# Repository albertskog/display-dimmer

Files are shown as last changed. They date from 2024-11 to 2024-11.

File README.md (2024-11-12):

# Display Dimmer

A pair of physical buttons to control the brightness of a pair of external monitors over HDMI.

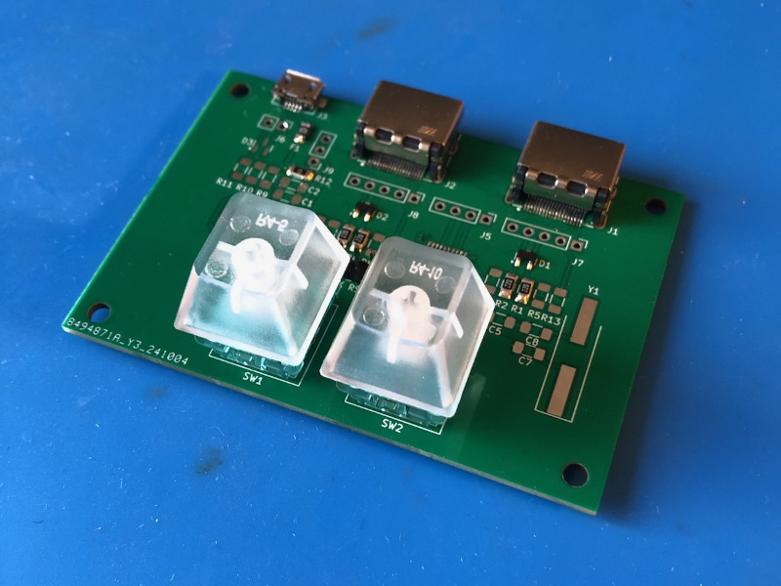
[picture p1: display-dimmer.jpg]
Display Dimmer hardware


## Why?

My USB-C port replicator does not pass on brightness commands to my monitors.

## How?

HDMI has a control channel called DDC. Hook this board up to a spare HDMI port on a monitor and use the buttons to control the brightness.

# Hardware Considerations

Here are some design considerations that were taken into account.

## VCC Voltage

The board has a footprint for a 3.3 V regulator and also a footprint for a 0 Ohm bypass to use 5 V directly from USB. HDMI signaling is 5 V and the CH32V003 can run at 5 V, but both also work at 3.3 V. I have used the 5 V option.

## Pull-up Resistors

On my monitors, the I2C lines are already pulled up to 5 V internally. The PCB has footprints for additional pull-up, but I found it works fine without populating them.

## USB

The board has a USB connector for power. The data lines are connected to GPIO pins for possible future use.

> Only GPIOs 0-4 can be used for USB D+/D- due to limits of the [c.andi](https://msyksphinz-self.github.io/riscv-isadoc/html/rvc.html#c-andi) instruction which can only hold a 5 bit value.
> You **cannot use** PC5-PC7 and PD5-PD7 for D+/D-!

[GitHub - cnlohr/rv003usb: CH32V003 RISC-V Pure Software USB Controller](https://github.com/cnlohr/rv003usb)

## BOM

| Amount | Part | Name | Source |
|---|---|---|---|
| 1x | MCU | CH32V003F4P6 | WCH on Aliexpress |
| 2x | HDMI connector | 685119134923 | [Electrokit](https://www.electrokit.com/hdmi-hona-19p-pcb-smd-wrth) |
| 1x | Micro USB connector | 629105136821 | [Electrokit](https://www.electrokit.com/usb-micro-b-kontakt-smd) |
| 2x | Buttons | MX-style | |
| 1x | Fuse | 1206L025YR | [Electrokit](https://www.electrokit.com/polyswitch-16v-0.25a-smd) |
| 4x | Protection resistor | 1206 22R | |
| 2x | ESD protection | NUP2105LT1G  | [Electrokit](https://www.electrokit.com/nup2105lt1g-sot23-3-tvs-diod) |
| 1x | 5 V bypass | 1206 0R | |

### Not mounted

| Amount | Part | Name | Source |
|---|---|---|---|
| 4x | Pull-up resistor | 1206 10K | |
| 1x | 3.3 V LDO | LDI1117-3.3H | [Electrokit](https://www.electrokit.com/ldi1117-3.3h-sot-223-spanningsregulator-ldo-3.3v) |
| 1x | Crystal 24 MHz | HC49/U4H | [Electrokit](https://www.electrokit.com/kristall-24.000mhz-smd-hc49/u4h) |

# Firmware

There are three firmware options:

1. The proof-of-concept written in Micropython on a Raspberry Pi RP2040.
2. The prototype firmware written in Platformio/Arduino C++ on a WCH CH32V003 devkit.
3. The final firmware written in Rust on the custom PCB.

## DDC Commands

DDC commands are hard-coded in the firmware. The payloads were generated from a slightly modified version of [python-ddcci](https://github.com/Informatic/python-ddcci)

| Command | Data |
|---|---|
| Set 0% | `[0x51, 0x84, 0x3, 0x10, 0x0, 0x0, 0xa8]` |
| Set 10% | `[0x51, 0x84, 0x3, 0x10, 0x0, 0xa, 0xa2]` |
| Set 20% | `[0x51, 0x84, 0x3, 0x10, 0x0, 0x14, 0xbc]` |
| Set 30% | `[0x51, 0x84, 0x3, 0x10, 0x0, 0x1e, 0xb6]` |
| Set 40% | `[0x51, 0x84, 0x3, 0x10, 0x0, 0x28, 0x80]` |
| Set 50% | `[0x51, 0x84, 0x3, 0x10, 0x0, 0x32, 0x9a]` |
| Set 60% | `[0x51, 0x84, 0x3, 0x10, 0x0, 0x3c, 0x94]` |
| Set 70% | `[0x51, 0x84, 0x3, 0x10, 0x0, 0x46, 0xee]` |
| Set 80% | `[0x51, 0x84, 0x3, 0x10, 0x0, 0x50, 0xf8]` |
| Set 90% | `[0x51, 0x84, 0x3, 0x10, 0x0, 0x5a, 0xf2]` |
| Set 100% | `[0x51, 0x84, 0x3, 0x10, 0x0, 0x64, 0xcc]` |
| Get (not used)| `[0x51, 0x82, 0x1, 0x10, 0xad]` |

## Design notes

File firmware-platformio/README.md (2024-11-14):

# Display Dimmer Firmware

This is the Arduino/Platformio version of the Display Dimmer firmware.

In order to remap the I2C peripheral of the CH32V003, the underlying Arduino core was patched to add the alternate pin mappings. If the following pull request has been merged, it should be possible to remove the custom `platform_package` in `platformio.ini`:

https://github.com/openwch/arduino_core_ch32/pull/152

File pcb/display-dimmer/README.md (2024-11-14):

# Display Dimmer PCB

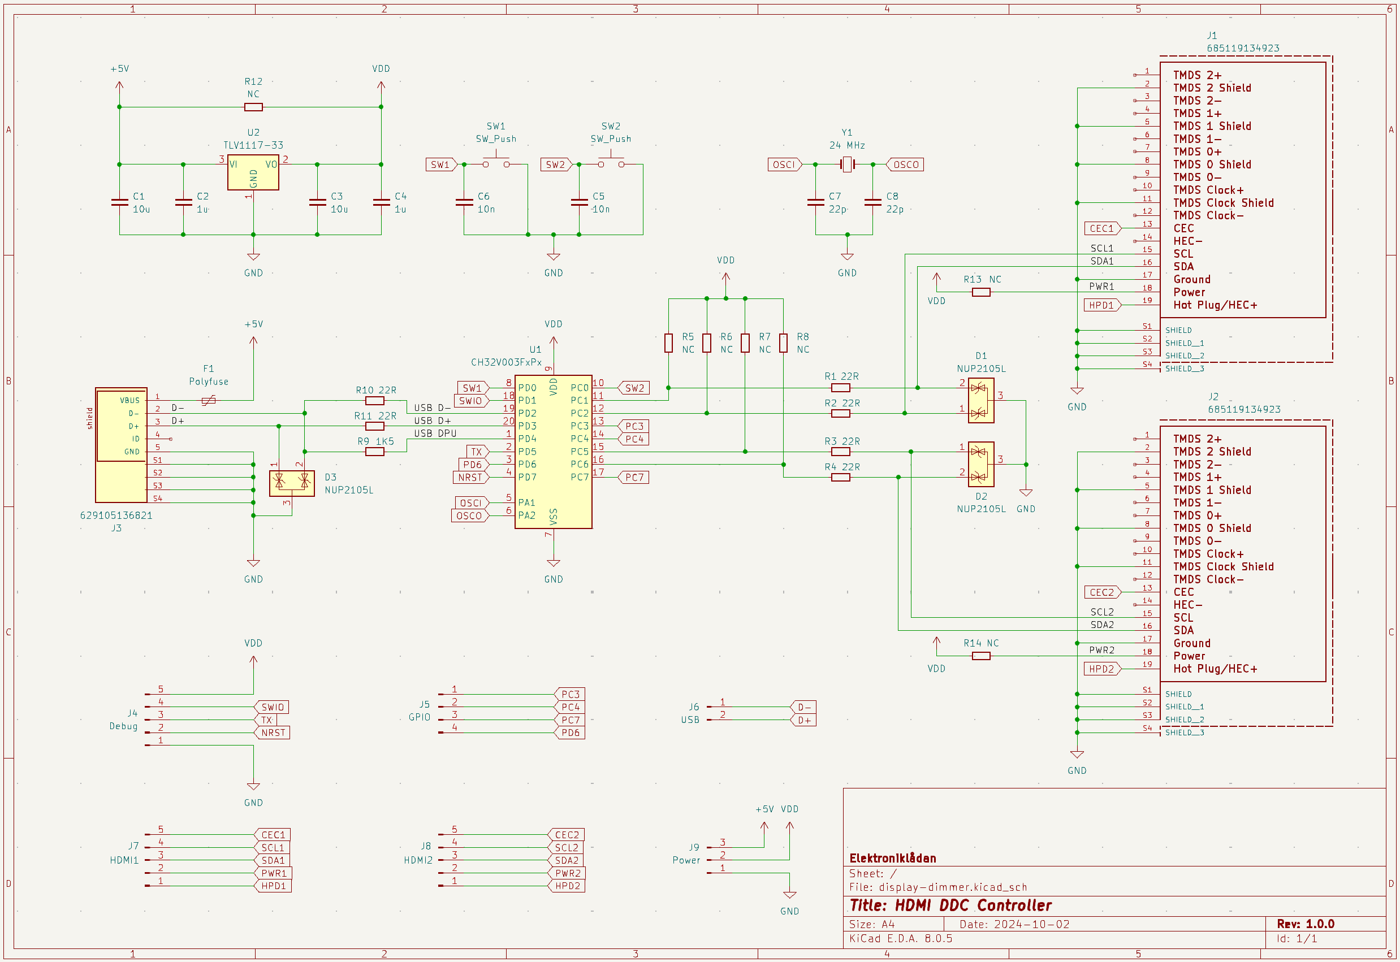
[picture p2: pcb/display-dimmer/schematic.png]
Picture of the schematic.


This folder contains the Kicad project files for the Display Dimmer PCB.

Unfortunatley, a couple of footprints from SnapEDA were used without realizing their license does not permit sharing. You will need to download them separatley:

- USB connector: https://www.digikey.se/en/models/2627271
- HDMI connector: https://www.digikey.se/en/models/2508506

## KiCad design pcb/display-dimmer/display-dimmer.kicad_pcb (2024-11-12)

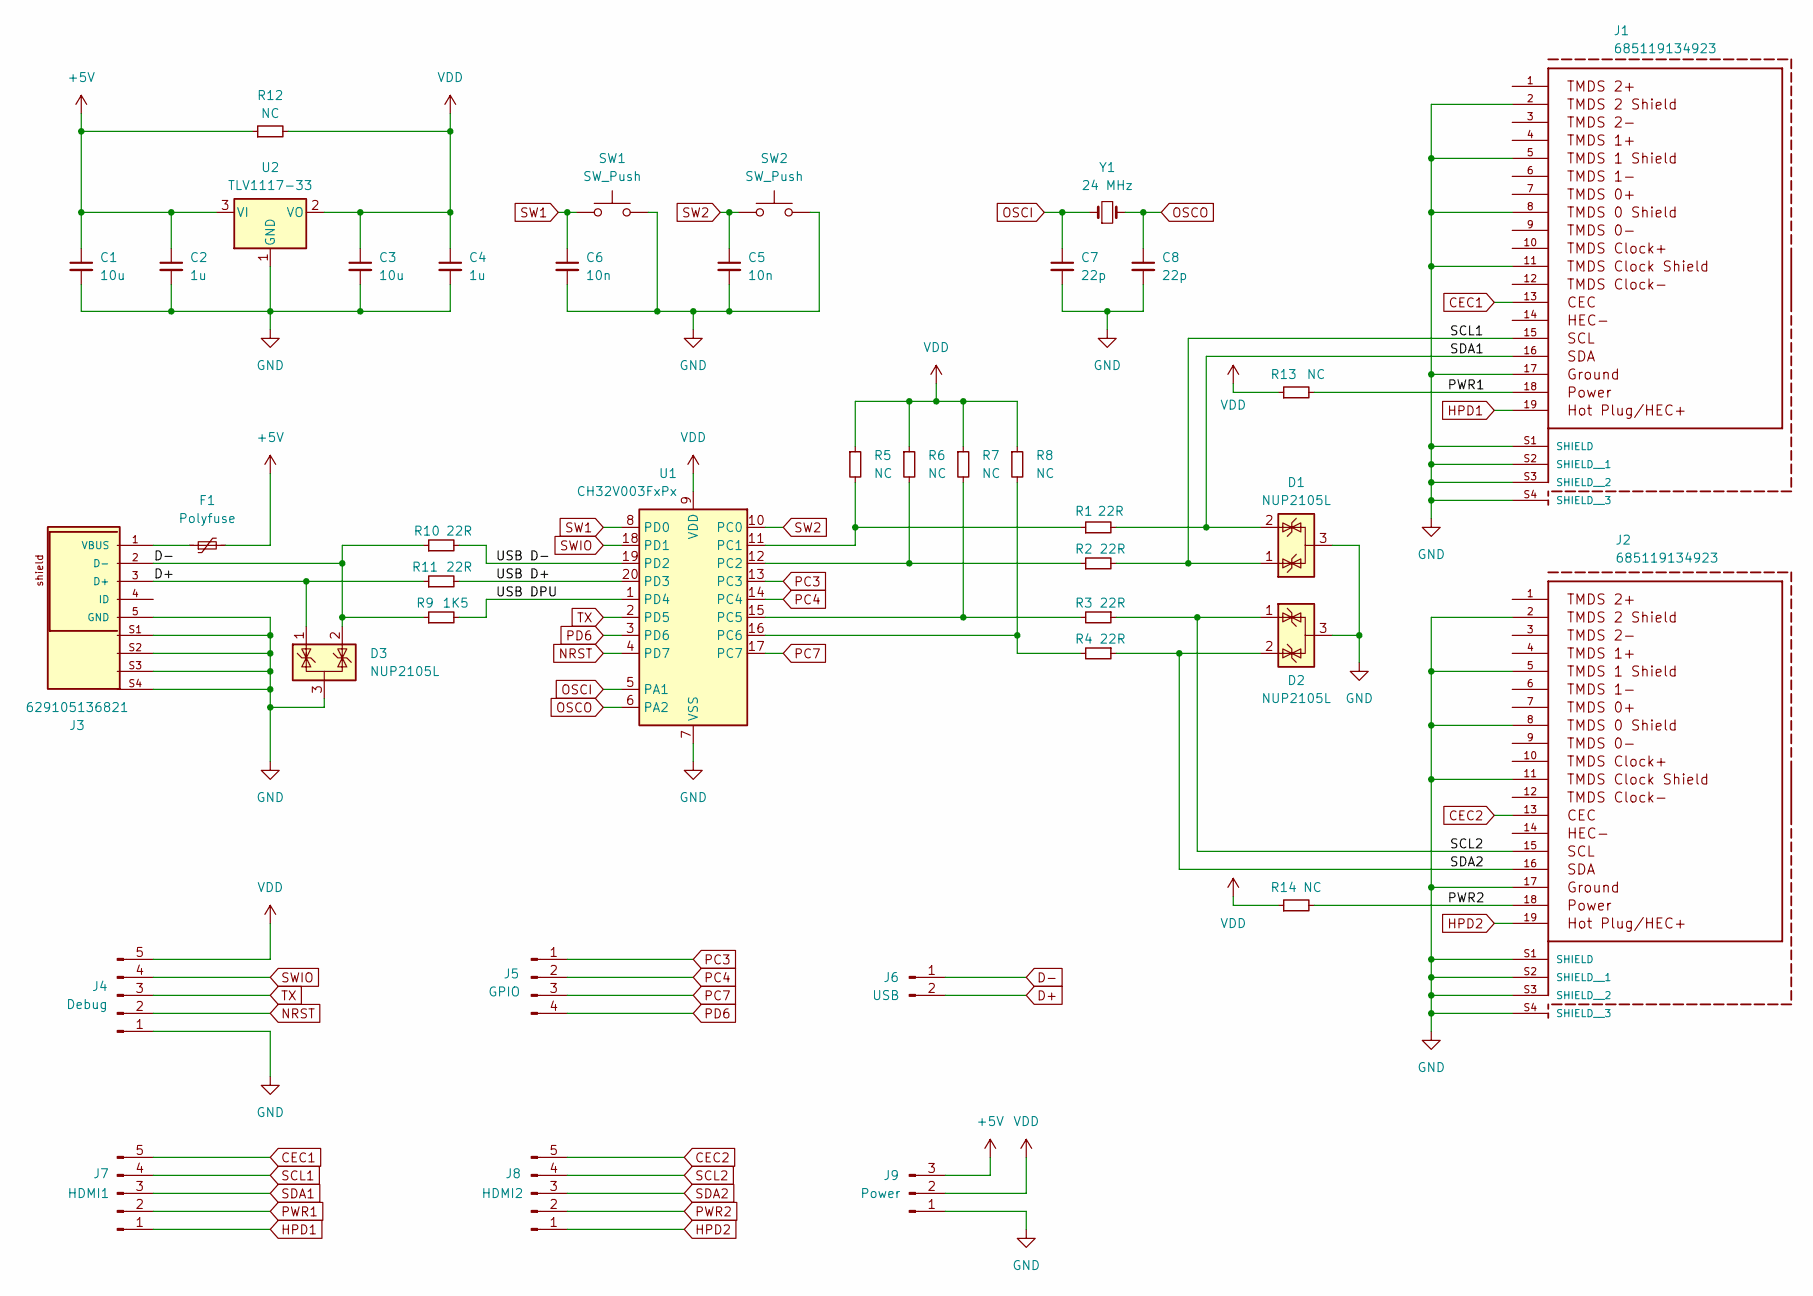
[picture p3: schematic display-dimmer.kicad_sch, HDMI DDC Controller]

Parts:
C1, C3: 10u; C_1206_3216Metric_Pad1.33x1.80mm_HandSolder
C2, C4: 1u; C_1206_3216Metric_Pad1.33x1.80mm_HandSolder
C5, C6: 10n; C_1206_3216Metric_Pad1.33x1.80mm_HandSolder
C7, C8: 22p; C_1206_3216Metric_Pad1.33x1.80mm_HandSolder
D1, D2, D3: NUP2105L; SOT-23
F1: Polyfuse; Fuse_1206_3216Metric_Pad1.42x1.75mm_HandSolder
J1, J2: 685119134923; PART-NUMBER 685119134923
J3: 629105136821; PART-NUMBER 629105136821
J4: Debug; PinHeader_1x05_P2.54mm_Vertical
J5: GPIO; PinHeader_1x04_P2.54mm_Vertical
J6: USB; PinHeader_1x02_P2.54mm_Vertical
J7: HDMI1; PinHeader_1x05_P2.54mm_Vertical
J8: HDMI2; PinHeader_1x05_P2.54mm_Vertical
J9: Power; PinHeader_1x03_P2.54mm_Vertical
R1, R2, R3, R4, R10, R11: 22R; R_1206_3216Metric_Pad1.30x1.75mm_HandSolder
R5, R6, R7, R8, R12, R13, R14: NC; R_1206_3216Metric_Pad1.30x1.75mm_HandSolder
R9: 1K5; R_1206_3216Metric_Pad1.30x1.75mm_HandSolder
SW1, SW2: SW_Push; SW_Cherry_MX_1.00u_PCB
U1: CH32V003FxPx; TSSOP-20_4.4x6.5mm_P0.65mm
U2: TLV1117-33; SOT-223-3_TabPin2
Y1: 24 MHz; Crystal_SMD_HC49-SD_HandSoldering

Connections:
+5V: C1.1, C2.1, F1.2, J9.3, R12.1, U2.3 (VI)
/USB D+: R11.2, U1.20 (PD3)
/USB D-: R10.2, U1.19 (PD2)
/USB DPU: R9.2, U1.1 (PD4)
CEC1: J1.13, J7.5
CEC2: J2.13, J8.5
D+: D3.1 (K), J3.3 (D+), J6.2, R11.1
D-: D3.2 (K), J3.2 (D-), J6.1, R9.1, R10.1
GND: C1.2, C2.2, C3.2, C4.2, C5.2, C6.2, C7.2, C8.2, D1.3 (A), D2.3 (A), D3.3 (A), J1.2, J1.5, J1.8, J1.11, J1.17, J1.S1 (SHIELD), J1.S2 (SHIELD__1), J1.S3 (SHIELD__2), J1.S4 (SHIELD__3), J2.2, J2.5, J2.8, J2.11, J2.17, J2.S1 (SHIELD), J2.S2 (SHIELD__1), J2.S3 (SHIELD__2), J2.S4 (SHIELD__3), J3.5 (GND), J3.S1, J3.S2, J3.S3, J3.S4, J4.1, J9.1, SW1.2, SW2.2, U1.7 (VSS), U2.1 (GND)
HPD1: J1.19, J7.1
HPD2: J2.19, J8.1
NRST: J4.2, U1.4 (PD7)
unnamed: F1.1, J3.1 (VBUS)
unnamed: R1.1, R5.2, U1.11 (PC1)
unnamed: R2.1, R6.2, U1.12 (PC2)
unnamed: R3.2, R7.2, U1.15 (PC5)
unnamed: R4.2, R8.2, U1.16 (PC6)
OSCI: C7.1, U1.5 (PA1), Y1.1
OSCO: C8.1, U1.6 (PA2), Y1.2
PC3: J5.1, U1.13 (PC3)
PC4: J5.2, U1.14 (PC4)
PC7: J5.3, U1.17 (PC7)
PD6: J5.4, U1.3 (PD6)
PWR1: J1.18, J7.2, R13.2
PWR2: J2.18, J8.2, R14.2
SCL1: D1.1 (K), J1.15, J7.4, R2.2
SCL2: D2.1 (K), J2.15, J8.4, R3.1
SDA1: D1.2 (K), J1.16, J7.3, R1.2
SDA2: D2.2 (K), J2.16, J8.3, R4.1
SW1: C6.1, SW1.1, U1.8 (PD0)
SW2: C5.1, SW2.1, U1.10 (PC0)
SWIO: J4.4, U1.18 (PD1)
TX: J4.3, U1.2 (PD5)
VDD: C3.1, C4.1, J4.5, J9.2, R5.1, R6.1, R7.1, R8.1, R12.2, R13.1, R14.1, U1.9 (VDD), U2.2 (VO)

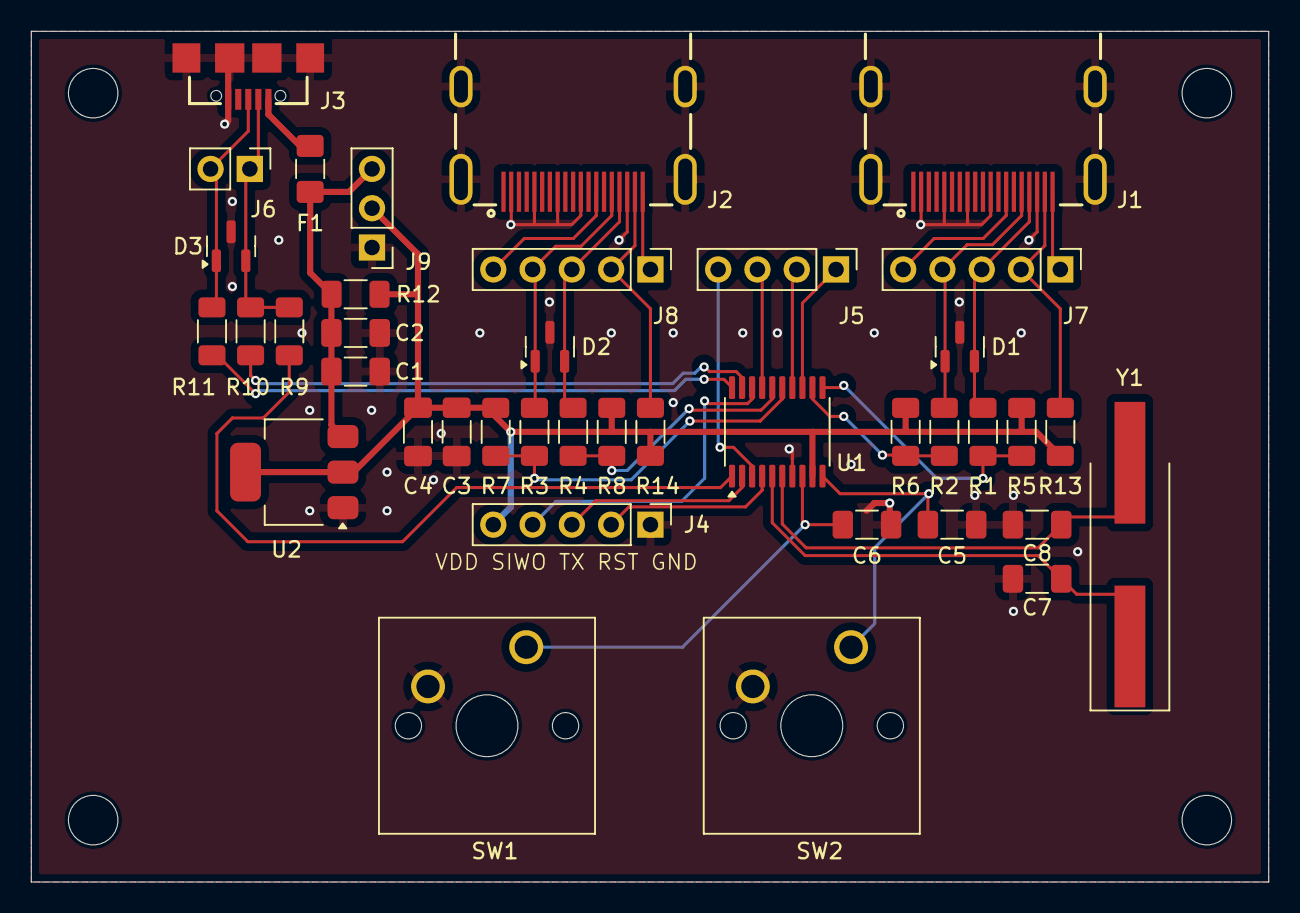
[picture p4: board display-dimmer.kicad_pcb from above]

Board: 2 copper layers, 80.0 x 55.0 mm, 40 parts (0 on the bottom side), 34 nets.

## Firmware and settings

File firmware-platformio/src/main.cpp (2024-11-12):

#include <Arduino.h>
#include <Wire.h>

#define PLUS PD0
#define MINUS PC0

#define ADDRESS 0x37

// Pre-computed commands for 0-100% brightness
uint8_t commands[11][7] = {
    {0x51, 0x84, 0x03, 0x10, 0x00, 0x00, 0xa8},
    {0x51, 0x84, 0x03, 0x10, 0x00, 0x0a, 0xa2},
    {0x51, 0x84, 0x03, 0x10, 0x00, 0x14, 0xbc},
    {0x51, 0x84, 0x03, 0x10, 0x00, 0x1e, 0xb6},
    {0x51, 0x84, 0x03, 0x10, 0x00, 0x28, 0x80},
    {0x51, 0x84, 0x03, 0x10, 0x00, 0x32, 0x9a},
    {0x51, 0x84, 0x03, 0x10, 0x00, 0x3c, 0x94},
    {0x51, 0x84, 0x03, 0x10, 0x00, 0x46, 0xee},
    {0x51, 0x84, 0x03, 0x10, 0x00, 0x50, 0xf8},
    {0x51, 0x84, 0x03, 0x10, 0x00, 0x5a, 0xf2},
    {0x51, 0x84, 0x03, 0x10, 0x00, 0x64, 0xcc}
};

TwoWire Display_A = TwoWire((uint32_t)PC1, (uint32_t)PC2);
TwoWire Display_B = TwoWire((uint32_t)PC6, (uint32_t)PC5);

int8_t brightness = 5;
int8_t change = 0;

void set(uint8_t *command){
    Display_A.begin((uint32_t)PC1, (uint32_t)PC2);
    Display_A.beginTransmission(ADDRESS);
    Display_A.write(command, 7);
    Display_A.endTransmission(true);
    Display_A.end();

    Display_B.begin((uint32_t)PC6, (uint32_t)PC5);
    Display_B.beginTransmission(ADDRESS);
    Display_B.write(command, 7);
    Display_B.endTransmission(true);
    Display_B.end();
}

void setup(){
    pinMode(PLUS, INPUT_PULLUP);
    pinMode(MINUS, INPUT_PULLUP);
}

void loop(){
    int8_t new_change = digitalRead(PLUS) - digitalRead(MINUS);

    if (new_change == 0){
        change = 0;
        return;
    }

    // Detect press and hold
    if (change == new_change){
        change = new_change * 10;
    }
    else {
        change = new_change;
    }

    int8_t new_brightness = constrain(brightness + change, 0, 10);
    
    if(brightness != new_brightness) {
        brightness = new_brightness;
        set(commands[brightness]);
    }

    delay(300);
}

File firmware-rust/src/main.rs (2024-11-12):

#![no_std]
#![no_main]

use ch32_hal as hal;
use ch32_hal::gpio::Input;
use hal::delay::Delay;
use hal::gpio::{Level, Output, Pull};
use hal::i2c;
use hal::i2c::I2c;
use hal::peripherals;
use hal::time::khz;

const COMMANDS: [[u8; 7]; 11] = [
    [0x51, 0x84, 0x03, 0x10, 0x00, 0x00, 0xa8],
    [0x51, 0x84, 0x03, 0x10, 0x00, 0x0a, 0xa2],
    [0x51, 0x84, 0x03, 0x10, 0x00, 0x14, 0xbc],
    [0x51, 0x84, 0x03, 0x10, 0x00, 0x1e, 0xb6],
    [0x51, 0x84, 0x03, 0x10, 0x00, 0x28, 0x80],
    [0x51, 0x84, 0x03, 0x10, 0x00, 0x32, 0x9a],
    [0x51, 0x84, 0x03, 0x10, 0x00, 0x3c, 0x94],
    [0x51, 0x84, 0x03, 0x10, 0x00, 0x46, 0xee],
    [0x51, 0x84, 0x03, 0x10, 0x00, 0x50, 0xf8],
    [0x51, 0x84, 0x03, 0x10, 0x00, 0x5a, 0xf2],
    [0x51, 0x84, 0x03, 0x10, 0x00, 0x64, 0xcc],
];

// SDI print requires the debugger to be connected.
// Set to false to run without debugger.
const DEBUG: bool = false;

macro_rules! debug_print {
    ($($arg:tt)*) => {
        if DEBUG {
            hal::println!($($arg)*);
        }
    }
}

struct Displays {
    i2c: peripherals::I2C1,
    scl_a: peripherals::PC2,
    sda_a: peripherals::PC1,
    scl_b: peripherals::PC5,
    sda_b: peripherals::PC6,
}

impl Displays {
    fn set(&mut self, command: &[u8; 7]) {
        let mut i2c_config = i2c::Config::default();
        i2c_config.timeout = embassy_time::Duration::from_millis(100);

        {
            let mut i2c = I2c::new_blocking(
                &mut self.i2c,
                &mut self.scl_a,
                &mut self.sda_a,
                khz(100),
                i2c_config,
            );
            i2c.blocking_write(0x37, command)
                .unwrap_or_else(|_| debug_print!("Write failed A"));
        }
        {
            let mut i2c = I2c::new_blocking(
                &mut self.i2c,
                &mut self.scl_b,
                &mut self.sda_b,
                khz(100),
                i2c_config,
            );
            i2c.blocking_write(0x37, command)
                .unwrap_or_else(|_| debug_print!("Write failed B"));
        }
    }
}

#[qingke_rt::entry]
fn main() -> ! {
    if DEBUG {
        hal::debug::SDIPrint::enable();
    }

    let mut config = hal::Config::default();
    
    config.rcc = hal::rcc::Config::SYSCLK_FREQ_48MHZ_HSI;
    
    let peripherals = hal::init(config);
    
    let mut delay = Delay;

    let mut i2c_config = i2c::Config::default();

    i2c_config.timeout = embassy_time::Duration::from_millis(100);

    let plus_button = Input::new(peripherals.PD0, Pull::Up);
    let minus_button = Input::new(peripherals.PC0, Pull::Up);

    let mut displays = Displays {
        i2c: peripherals.I2C1,
        scl_a: peripherals.PC2,
        sda_a: peripherals.PC1,
        scl_b: peripherals.PC5,
        sda_b: peripherals.PC6,
    };
    
    let mut brightness: i8 = 5;
    let mut change: i8 = 0;

    debug_print!("Start");
    loop {
        let new_change = (plus_button.is_high() as i8) - (minus_button.is_high() as i8);

        if new_change == 0 {
            change = 0;
            continue;
        }

        // Detect press and hold
        if change == new_change {
            change = new_change * 10;
        }
        else {
            change = new_change;
        }

        let new_brightness = (brightness + change).clamp(0, 10);
    
        if brightness != new_brightness {
            brightness = new_brightness;
            displays.set(&COMMANDS[brightness  as usize]);
        }

        // Crude debounce and press/hold delay
        delay.delay_ms(300);
    }
}

#[panic_handler]
fn panic(info: &core::panic::PanicInfo) -> ! {
    let _ = debug_print!("\n{}", info);
    loop {}
}

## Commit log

2024-11-12 Add project files
    [display-dimmer.kicad_pcb, display-dimmer.kicad_sch]
2024-11-14 Add patched Arduino core to config file and add readme
